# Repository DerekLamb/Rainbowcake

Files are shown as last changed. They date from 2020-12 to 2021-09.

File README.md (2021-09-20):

# Rainbowcake
RGB split keyboard based on Lily58/Sofle and Corne keyboards  
*Currently on first revision*
*Making changes to qmk layout*  

Couldn't find the keyboard for me, so I made it.  

Based on Sofle/Lily58, with Corne style key backlighting  

Designed to use screws and locknuts to tent. 

* ~~PCB ordered on 12/17 from JLCPCB.com~~
* ~~Partially Assembled~~
* ~~Flashed QMK~~
* Need to make changes to layout

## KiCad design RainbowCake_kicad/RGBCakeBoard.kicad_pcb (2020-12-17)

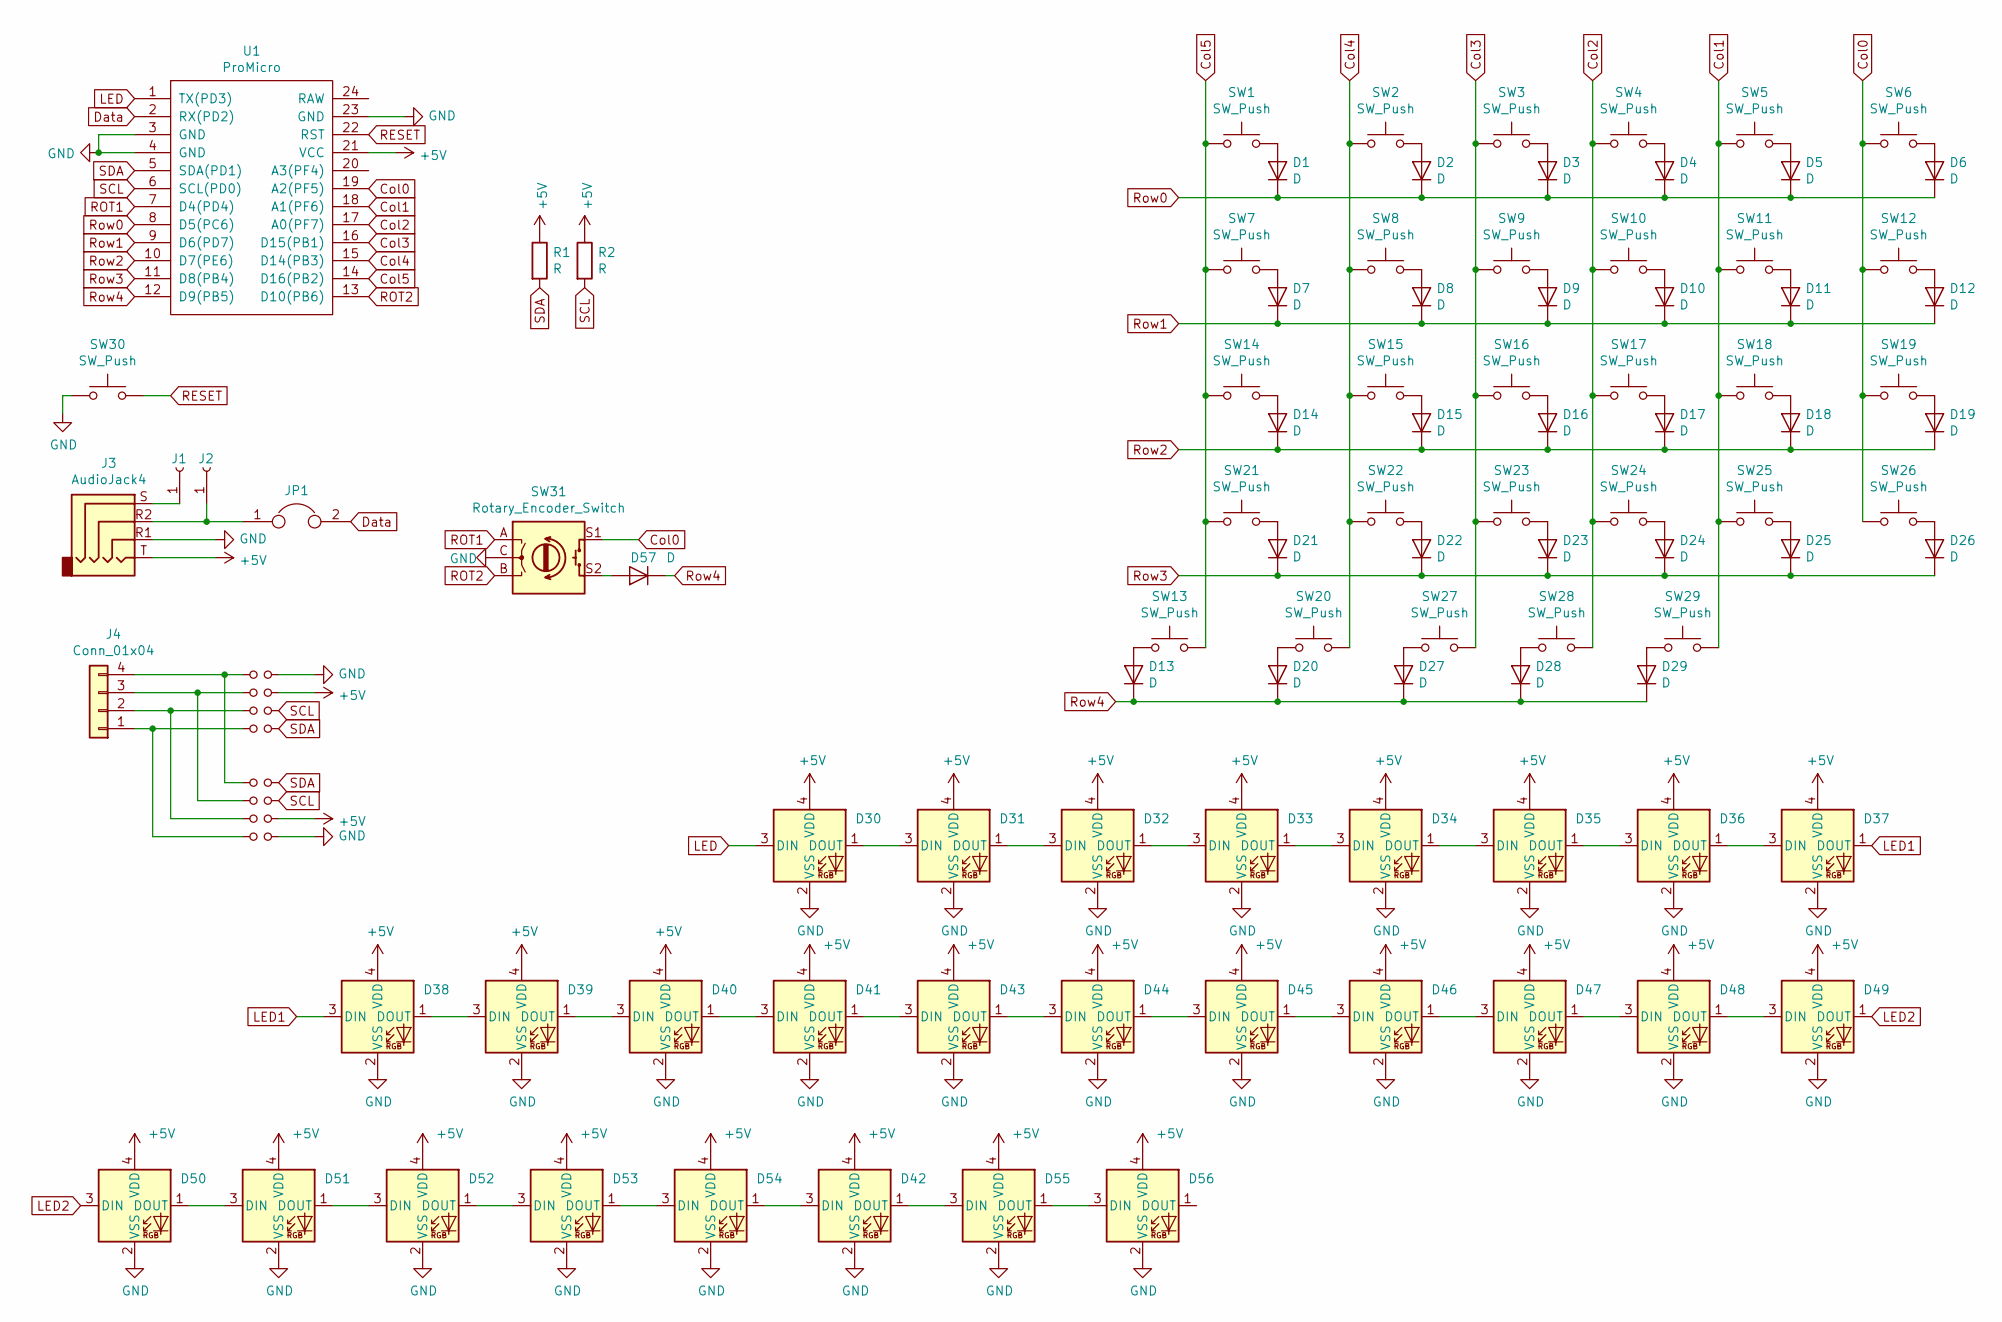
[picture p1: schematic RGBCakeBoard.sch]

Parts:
D1, D2, D3, D4, D5, D6, D7, D8, D9, D10, D11, D12, D13, D14, D15, D16, D17, D18, D19, D20, D21, D22, D23, D24, D25, D26, D27, D28, D29, D57: D; Diode_SOD123_Doublesided_Universal
D30, D31, D32, D33, D34, D35, D36, D37, D38, D39, D40, D41, D42, D43, D44, D45, D46, D47, D48, D49, D50, D51, D52, D53, D54, D55, D56: SK6812MINI; SK6812MINI_Cutout
J1, J2: Conn_01x01_Female; SolderWirePad_1x01_Drill1mm
J3: AudioJack4; MJ-4PP-9
J4: Conn_01x04; PinHeader_1x04_P2.54mm_Vertical
JP1: Jumper; SolderJumper-2_P1.3mm_Bridged_RoundedPad1.0x1.5mm
JP2, JP3, JP4, JP5, JP6, JP7, JP8, JP9: Jumper_NO_Small; SolderJumper-2_P1.3mm_Open_RoundedPad1.0x1.5mm
R1, R2: R; R_Axial_DIN0207_L6.3mm_D2.5mm_P10.16mm_Horizontal
SW1, SW2, SW3, SW4, SW5, SW6, SW7, SW8, SW9, SW10, SW11, SW12, SW13, SW14, SW15, SW16, SW17, SW18, SW19, SW20, SW21, SW22, SW23, SW24, SW25, SW26, SW27, SW28, SW29: SW_Push; CherryMX_KailhLowProfile_Hotswap_edge
SW30: SW_Push; SW_Push_1P1T_NO_CK_KMR2
SW31: Rotary_Encoder_Switch; XDCR_PEC11R-4215F
U1: ProMicro; ProMicro_rev2

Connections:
+5V: D30.4 (VDD), D31.4 (VDD), D32.4 (VDD), D33.4 (VDD), D34.4 (VDD), D35.4 (VDD), D36.4 (VDD), D37.4 (VDD), D38.4 (VDD), D39.4 (VDD), D40.4 (VDD), D41.4 (VDD), D42.4 (VDD), D43.4 (VDD), D44.4 (VDD), D45.4 (VDD), D46.4 (VDD), D47.4 (VDD), D48.4 (VDD), D49.4 (VDD), D50.4 (VDD), D51.4 (VDD), D52.4 (VDD), D53.4 (VDD), D54.4 (VDD), D55.4 (VDD), D56.4 (VDD), J3.T, JP3.2, JP8.2, R1.1, R2.1, U1.21 (VCC); also elsewhere on the board
Col0: SW6.1, SW12.1, SW19.1, SW26.1, SW31.S1, U1.19 (A2(PF5))
Col1: SW5.1, SW11.1, SW18.1, SW25.1, SW29.2, U1.18 (A1(PF6))
Col2: SW4.1, SW10.1, SW17.1, SW24.1, SW28.2, U1.17 (A0(PF7))
Col3: SW3.1, SW9.1, SW16.1, SW23.1, SW27.2, U1.16 (D15(PB1))
Col4: SW2.1, SW8.1, SW15.1, SW20.2, SW22.1, U1.15 (D14(PB3))
Col5: SW1.1, SW7.1, SW13.2, SW14.1, SW21.1, U1.14 (D16(PB2))
Data: JP1.2, U1.2 (RX(PD2))
GND: D30.2 (VSS), D31.2 (VSS), D32.2 (VSS), D33.2 (VSS), D34.2 (VSS), D35.2 (VSS), D36.2 (VSS), D37.2 (VSS), D38.2 (VSS), D39.2 (VSS), D40.2 (VSS), D41.2 (VSS), D42.2 (VSS), D43.2 (VSS), D44.2 (VSS), D45.2 (VSS), D46.2 (VSS), D47.2 (VSS), D48.2 (VSS), D49.2 (VSS), D50.2 (VSS), D51.2 (VSS), D52.2 (VSS), D53.2 (VSS), D54.2 (VSS), D55.2 (VSS), D56.2 (VSS), J3.R1, JP2.2, JP9.2, SW30.1, SW31.C, U1.3 (GND), U1.4 (GND), U1.23 (GND); also elsewhere on the board
LED: D30.3 (DIN), U1.1 (TX(PD3))
LED1: D37.1 (DOUT), D38.3 (DIN)
LED2: D49.1 (DOUT), D50.3 (DIN)
unnamed: D1.2 (A), SW1.2
unnamed: D2.2 (A), SW2.2
unnamed: D3.2 (A), SW3.2
unnamed: D4.2 (A), SW4.2
unnamed: D5.2 (A), SW5.2
unnamed: D6.2 (A), SW6.2
unnamed: D7.2 (A), SW7.2
unnamed: D8.2 (A), SW8.2
unnamed: D9.2 (A), SW9.2
unnamed: D10.2 (A), SW10.2
unnamed: D11.2 (A), SW11.2
unnamed: D12.2 (A), SW12.2
unnamed: D13.2 (A), SW13.1
unnamed: D14.2 (A), SW14.2
unnamed: D15.2 (A), SW15.2
unnamed: D16.2 (A), SW16.2
unnamed: D17.2 (A), SW17.2
unnamed: D18.2 (A), SW18.2
unnamed: D19.2 (A), SW19.2
unnamed: D20.2 (A), SW20.1
unnamed: D21.2 (A), SW21.2
unnamed: D22.2 (A), SW22.2
unnamed: D23.2 (A), SW23.2
unnamed: D24.2 (A), SW24.2
unnamed: D25.2 (A), SW25.2
unnamed: D26.2 (A), SW26.2
unnamed: D27.2 (A), SW27.1
unnamed: D28.2 (A), SW28.1
unnamed: D29.2 (A), SW29.1
unnamed: D30.1 (DOUT), D31.3 (DIN)
unnamed: D31.1 (DOUT), D32.3 (DIN)
unnamed: D32.1 (DOUT), D33.3 (DIN)
unnamed: D33.1 (DOUT), D34.3 (DIN)
unnamed: D34.1 (DOUT), D35.3 (DIN)
unnamed: D35.1 (DOUT), D36.3 (DIN)
unnamed: D36.1 (DOUT), D37.3 (DIN)
unnamed: D38.1 (DOUT), D39.3 (DIN)
unnamed: D39.1 (DOUT), D40.3 (DIN)
unnamed: D40.1 (DOUT), D41.3 (DIN)
unnamed: D41.1 (DOUT), D43.3 (DIN)
unnamed: D42.1 (DOUT), D55.3 (DIN)
unnamed: D42.3 (DIN), D54.1 (DOUT)
unnamed: D43.1 (DOUT), D44.3 (DIN)
unnamed: D44.1 (DOUT), D45.3 (DIN)
unnamed: D45.1 (DOUT), D46.3 (DIN)
unnamed: D46.1 (DOUT), D47.3 (DIN)
unnamed: D47.1 (DOUT), D48.3 (DIN)
unnamed: D48.1 (DOUT), D49.3 (DIN)
unnamed: D50.1 (DOUT), D51.3 (DIN)
unnamed: D51.1 (DOUT), D52.3 (DIN)
unnamed: D52.1 (DOUT), D53.3 (DIN)
unnamed: D53.1 (DOUT), D54.3 (DIN)
unnamed: D55.1 (DOUT), D56.3 (DIN)
unnamed 65: D56.1 (DOUT); also elsewhere on the board
unnamed: D57.2 (A), SW31.S2
unnamed: J1.1, J3.S
unnamed: J2.1, J3.R2, JP1.1
unnamed: J4.1, JP5.1, JP9.1
unnamed: J4.2, JP4.1, JP8.1
unnamed: J4.3, JP3.1, JP7.1
unnamed: J4.4, JP2.1, JP6.1
RESET: SW30.2, U1.22 (RST)
ROT1: SW31.A, U1.7 (D4(PD4))
ROT2: SW31.B, U1.13 (D10(PB6))
Row0: D1.1 (K), D2.1 (K), D3.1 (K), D4.1 (K), D5.1 (K), D6.1 (K), U1.8 (D5(PC6))
Row1: D7.1 (K), D8.1 (K), D9.1 (K), D10.1 (K), D11.1 (K), D12.1 (K), U1.9 (D6(PD7))
Row2: D14.1 (K), D15.1 (K), D16.1 (K), D17.1 (K), D18.1 (K), D19.1 (K), U1.10 (D7(PE6))
Row3: D21.1 (K), D22.1 (K), D23.1 (K), D24.1 (K), D25.1 (K), D26.1 (K), U1.11 (D8(PB4))
Row4: D13.1 (K), D20.1 (K), D27.1 (K), D28.1 (K), D29.1 (K), D57.1 (K), U1.12 (D9(PB5))
SCL: JP4.2, JP7.2, R2.2, U1.6 (SCL(PD0))
SDA: JP5.2, JP6.2, R1.2, U1.5 (SDA(PD1))

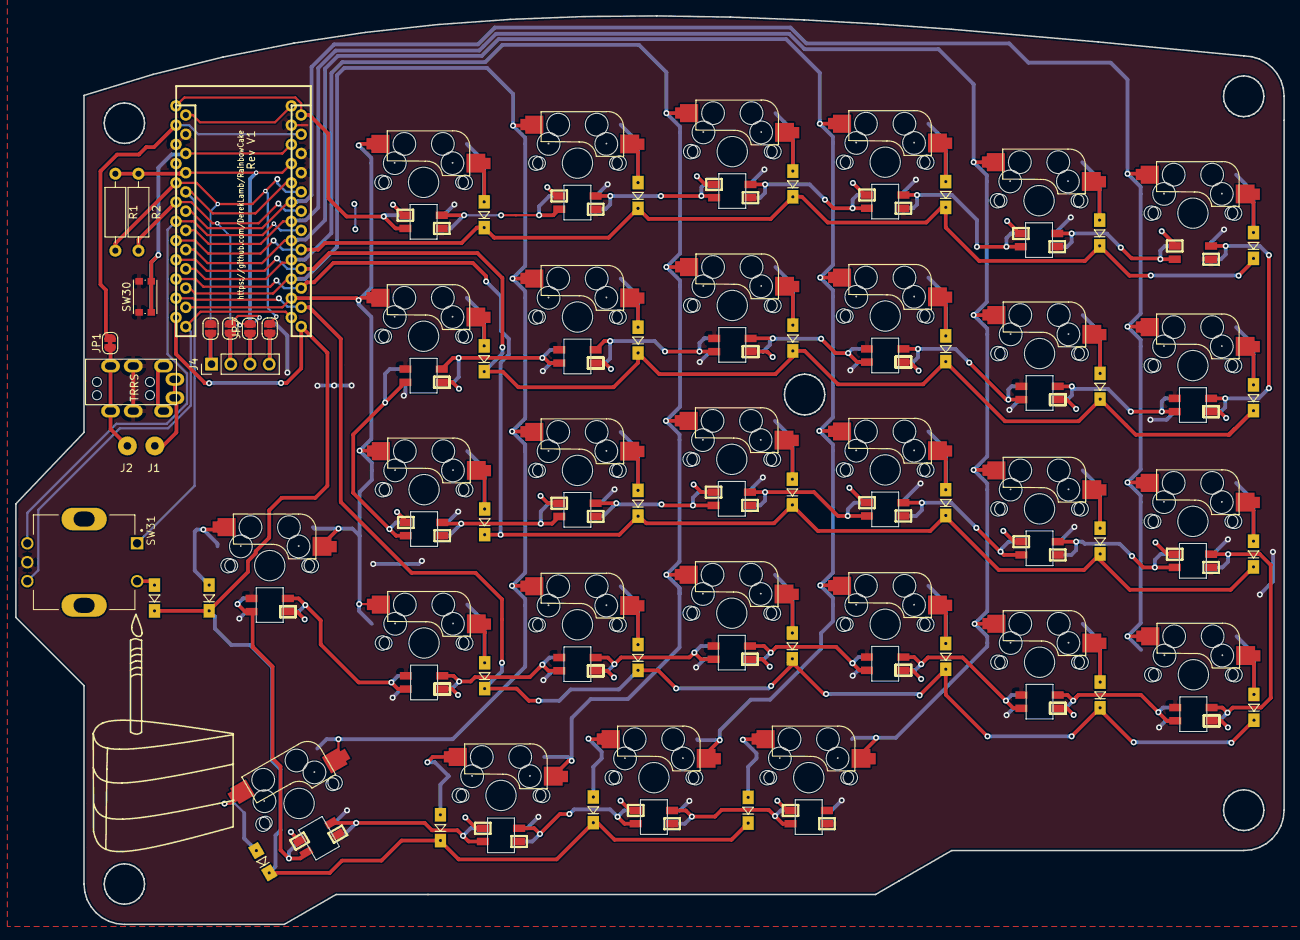
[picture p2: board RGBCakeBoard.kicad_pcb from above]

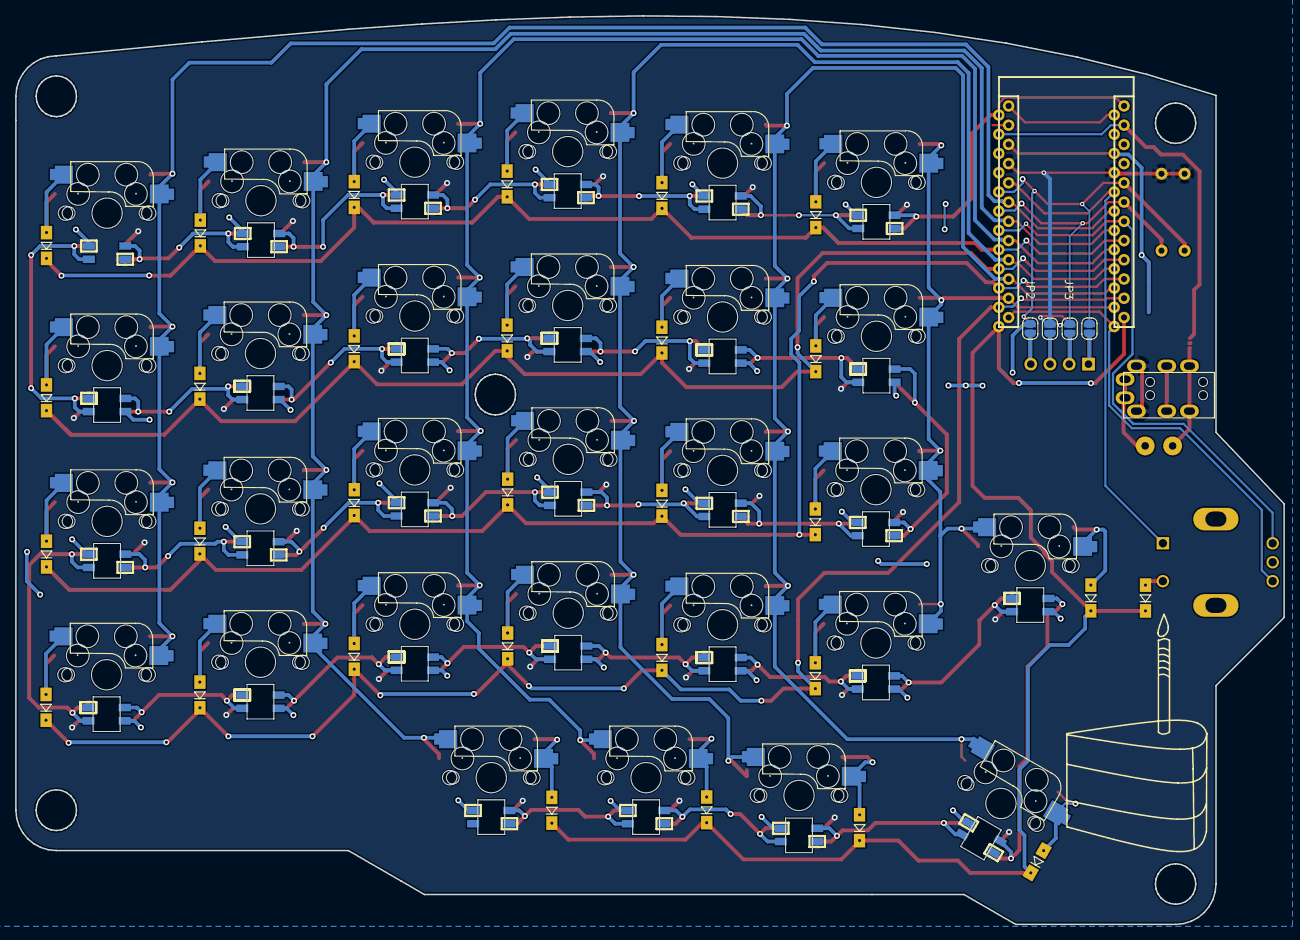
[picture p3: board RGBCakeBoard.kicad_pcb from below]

Board: 2 copper layers, 167.5 x 120.0 mm, 106 parts (4 on the bottom side), 84 nets.

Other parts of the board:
D57#2, D58: SK6812MINI; SK6812MINI_Cutout

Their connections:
+5V: D57#2.4, D58.4; also elsewhere on the board
GND: D57#2.2, D58.2; also elsewhere on the board
unnamed 65: D57#2.3; also elsewhere on the board
unnamed: D57#2.1, D58.3
